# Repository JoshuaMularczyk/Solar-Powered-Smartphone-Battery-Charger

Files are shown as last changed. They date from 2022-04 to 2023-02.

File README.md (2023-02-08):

# Solar Smartphone Charger
This project applies skills of Power Electronics to create, deign, and construct a solar powered battery charger. My partner [Christian Williams](https://github.com/cwill713) and I were tasked by our professor [Dr. Rob Frohne](https://github.com/frohro) with coming up with a project for our Power Electronics class that incorporated what we were learning in the coursework. We decided to take what we were learning about step-down converters and design a charger for a smartphone in which the power source was a solar panel.

## Design Objectives:
- Output 5V from a higher input voltage
- Allow 1 amphere to be drawn into the smartphone
- Inexpensive to build ($20-$30 Budget)

## Overview

Blockdiagram

The power electronics project that [Christian Williams](https://github.com/cwill713) and I decided on was based around the specifications of new generation iPhone. We knew that Apple is picky with their products, so if we could get it to work with an iPhone it should, in theory, work with Android as well. I decided to use the [LM3478](https://www.ti.com/lit/ds/symlink/lm3478.pdf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) High-Efficiency Low-Side N-Channel Controller for our Switching Regulator. This is the heart of our circuit and allows for a reccomended 2.97-40V input volage and a peak driver output current of 1A. This chip can withstand a typical input current of 2.7A and a max of 3.3A. We used a 5W 12V Solar Panel to ensure that our smartphone would charge in average conditions.

## Rev 7 Design

schematic2

This is the most updated KiCad schematic for my circuit design. I used the Texas Instrument [Webench Power Designer](https://www.ti.com/design-resources/design-tools-simulation/webench-power-designer.html) to generate this step-down circuit. I used the majority of the components specified by the power designer with the exception of some values. These can be found in the [BOM](https://github.com/JoshuaMularczyk/Solar-Smartphone-Charger/tree/main/BOMs) I specified a 5V minimum as well as a 12V maximum based on what would most likely be coming out of the solar panel. I also specified 1A for my maximum output current and 5V for my output voltage. The efficiency of this circuit was given at 84.1% by Webench.

### Voltage Dividers for USB

volatgefix2applereq

The voltages that needed to be applied to the Vbus, D+, and D- pin were found in the following websites: [Pinout for USB](http://static.righto.com/files/charger-schematic.pdf) and [Values based on different Ampheres](https://kb.plugable.com/usb-hubs-cables-switches/usb-device-charging). *Note since we are using 1A ouput the Vbus pin needs 5V, the D- pin needs 2V, and the D+ pin needs 2.7V*
## Rev 7 Simulation
I simulated our circuit in LTSpice

labeledsim

LTSpice has most of the components needed, but I had to import a library for the LM3478. I found this library in a [project log](https://hackaday.io/project/27899-nixie-tube-power-supply/log/69767-ltspice) by [Paul Andrews](https://github.com/judge2005) on Hackaday. That library was causeing some errors in LTSpice so I did some research and realized I needed to add two more "0" place holders after each "PULSE" statement. The updated library that I used LM3478 can be downloaded [here](https://github.com/JoshuaMularczyk/Solar-Smartphone-Charger/blob/main/Simulations/LM3478_TRANS.lib). The second library I needed was for the csd17553q5a mosfet. I found this library on the [Texas Instrument](https://www.ti.com/product/CSD17553Q5A#design-tools-simulation) page. This library can be downloaded [here](https://github.com/JoshuaMularczyk/Solar-Smartphone-Charger/blob/main/Simulations/CSD17553Q5A.lib). The schottkey diode used in the simulation is also not the exact same component as used in the schematic but another schottkey diode with the same specifications was used in its place. The simulation ran over night to get to 7 ms. The prolonged period of time was likely due to the laptop it was running on as well as the coupled inductors in the circuit.

### Voltage Outputs (5V 2.7V 2V)

labeledvoltages

This simulation shows the voltages going into each of our three USB output pins (5V, 2.7V, 2V).

### Input and Output Current

currentsim

This simulation shows the two different currents in our circuit. The green trace represents the current going into the LM3478. It starts at about 270mA and trails off close to 0A. The blue trace represents the current being pulled from the 5-ohm load resistor which is taking the place of an iPhone. The iPhone needs to draw around 1A of current and as seen in the simulation it will achieve this.

## Rev 7 PCB Design

pcb2

We had our boards sourced from [JLCPCB](https://jlcpcb.com/VGS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), who have an offer going of 5, 2-layer, 100x100mm boards for $2. I then designed the board to fit these specifications and send it in for printing.

## Rev 6 Testing

My partner and I decided to construct a [Build and Test Plan](https://github.com/JoshuaMularczyk/Solar-Smartphone-Charger/blob/main/Milestone%20Reports/Build%20and%20Test%20Plan.xlsx) while we waited for our parts to come in from JLCPCB and Digikey. It helped us think through ways of testing things in stages without causing the destructions of parts.



My partner and I each constructed a separate board and tested to see if it worked. After constructing the boards we used a 0-18V 1A power supply and realized that the boards were not allowing our iPhones to charge. We plugged in a nearby TI-84 Plus CE calculator that was rated to charge at 5V 0.5A and it started charging. We then decided to switch to a bigger power supply rated for 24V 3A and plugged in an Android which began to charge. The iPhone still would not charge. After some research about Apple devices, a fellow colleague, [Caydn Maddocks](https://github.com/Maddca) and I discovered that Apple was extra particular and required voltages to the D+ and D- pins of the USB connector. The specific voltages differ based on the current being drawn (we used 2.7V to D+ and 2V to D-). This can be seen in the "Voltage Dividers for USB" section above. The process of fixing this can be seen in the issues section [here](https://github.com/JoshuaMularczyk/Solar-Smartphone-Charger/issues?q=is%3Aissue+is%3Aclosed).

Next, we connected our 5W 12V solar panels to the converter and took them outside to get direct sunlight. Once the solar panel was propped up to be perpendicular to the sun, I plugged in my iPhone and it started charging. It takes quite a bit of time to charge with 5W so I recommend getting a higher wattage solar panel for faster charging.

## Rev 6 Results

The image on the left shows the voltage being supplied to the iPhone and the image on the right shows the current being drawn by the iPhone.



Here we can see that using the power supply, our circuits is around 93.7% efficient ((4.88V*0.96A)/(5W)). We also tested this circuit with voltages from 5-12V from the power supply and the output stayed at a constant 4.8-4.9V.

The Solar Smartphone Charger worked as expected and was able to charge smartphones, Apple and Android, during a sunny day. You can see more photos of the finished product on the [wiki](https://github.com/JoshuaMularczyk/Solar-Smartphone-Charger/wiki/Photos) here!

We measured a 4.74V 0.98A output from our circuit using a solar panel. This gives us an efficiency of 92.9% given that our solar panel was actually outputting 5W.

Click [here](https://youtu.be/SS7m2UqrDPg) to watch a video demonstration of the finished project!

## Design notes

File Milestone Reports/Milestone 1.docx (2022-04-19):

Joshua Mularczyk and Christian Williams

ENGR 460

Milestone 1

4 April 2022

Project Definition

Project: Solar powered phone charger

Stretch Goal: Make it a wireless charger

Definition:

For our project this quarter, we have decided to design power electronics to use solar power to charge a smartphone. This will be done using solar panels that will provide charge to a external rechargeable battery (maybe 2 AA’s?) which will then run through circuitry that has some type of switch that shuts off the charging when the maximum voltage has been reached and circuitry to allow the power to pass from the batteries through a USB port so that a smart phone can be plugged in. If time allows, a casing can be designed for the circuitry using 3D printing for a final portable product.

References that sparked idea:

https://www.youtube.com/watch?v=OyslcihUtzQ

- Youtube video explaining how to create a DC to DC Boost Converter

https://www.instructables.com/Wireless-Solar-Charger/

- Project using solar panels to create a wireless charger for a smartphone

https://www.engineeringforchange.org/news/how-to-build-a-solar-powered-usb-charger-for-phones-and-other-small-devices/

- Shows the process of designing a similar solar powered phone charger

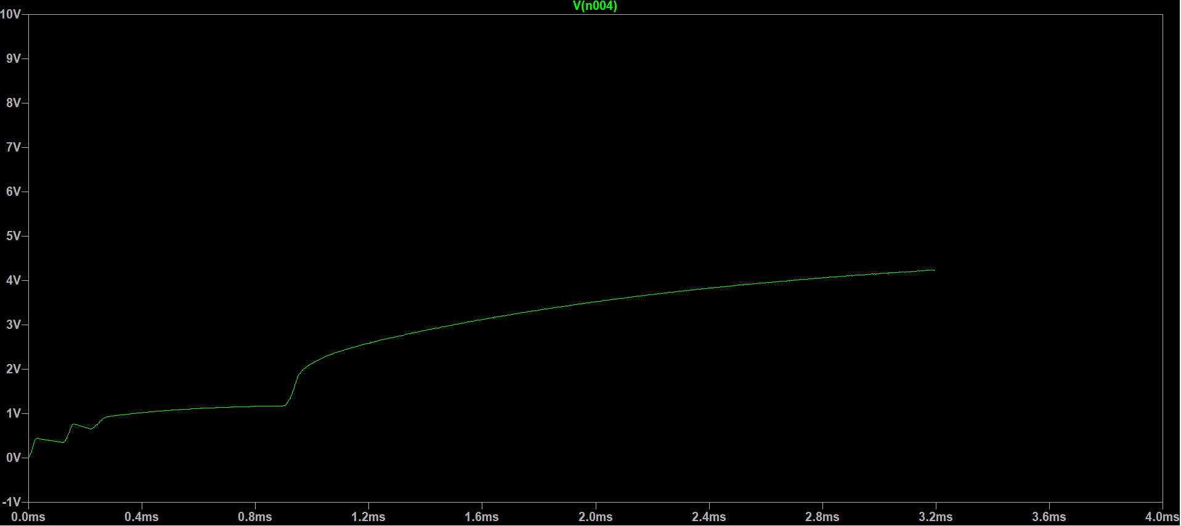
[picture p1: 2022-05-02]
Simulations/Pictures of Output Voltage/LoadResistorSimClose.PNG

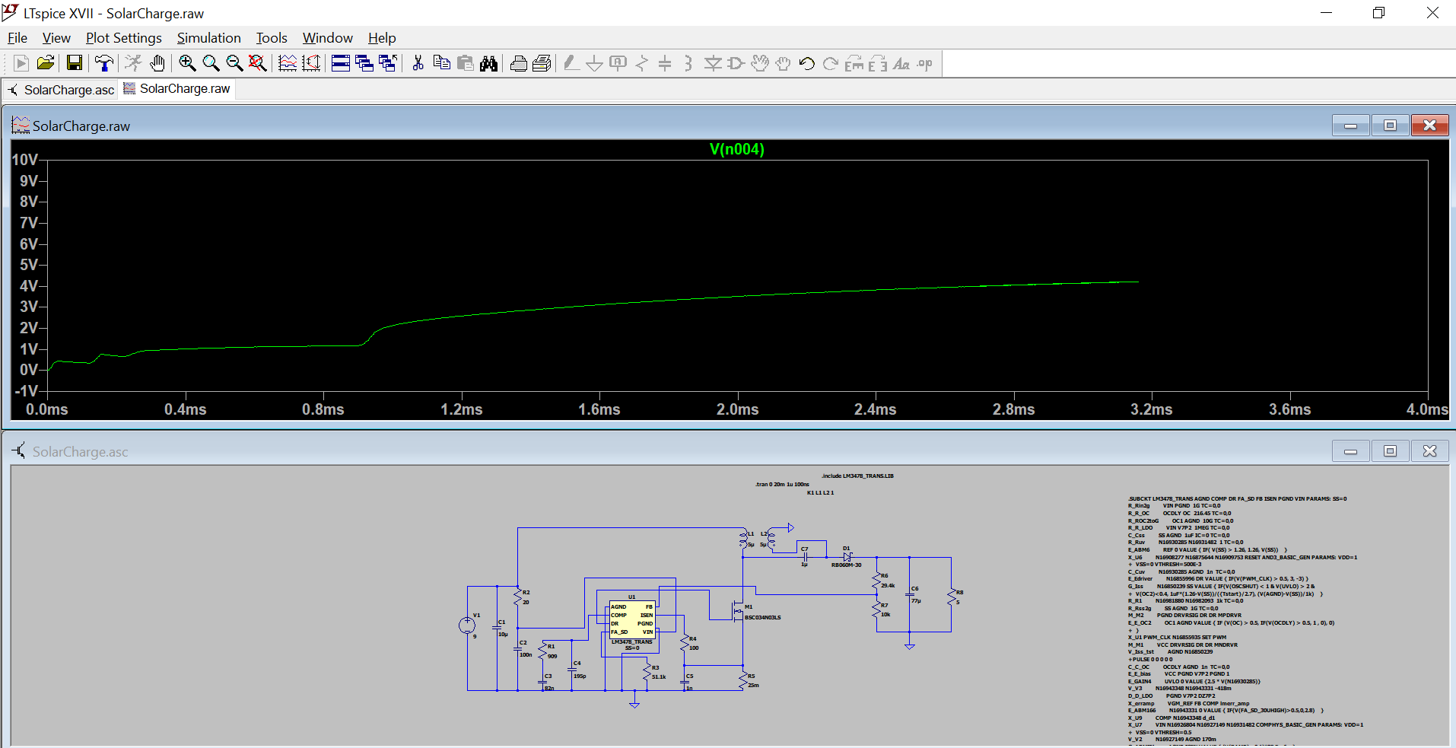
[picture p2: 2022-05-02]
Simulations/Pictures of Output Voltage/loadResistorSim.PNG

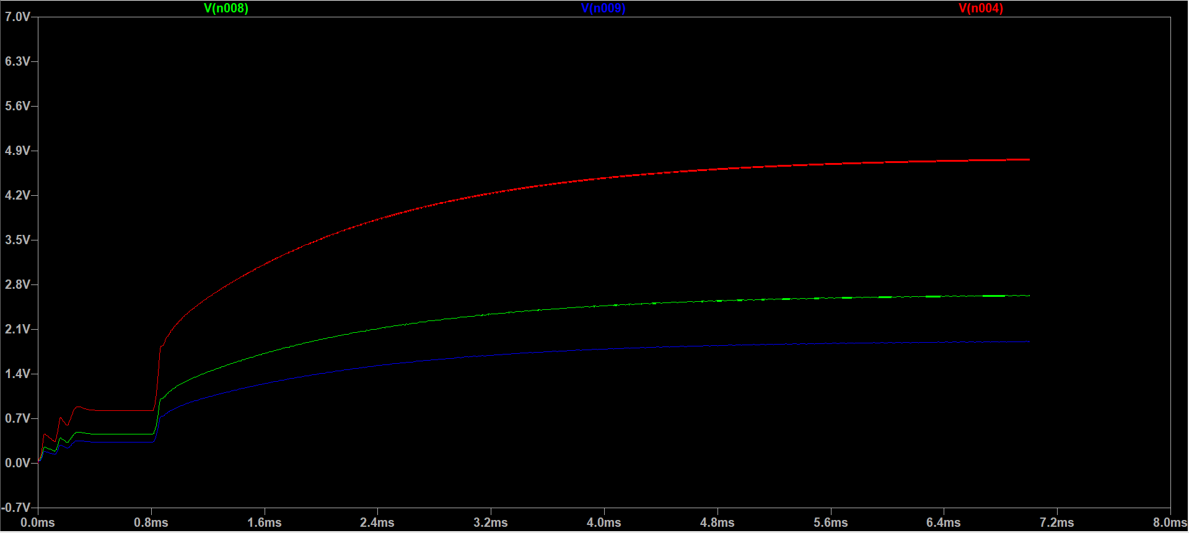
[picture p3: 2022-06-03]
Simulations/Pictures of Output Voltage/ThreeOutputVoltages.PNG

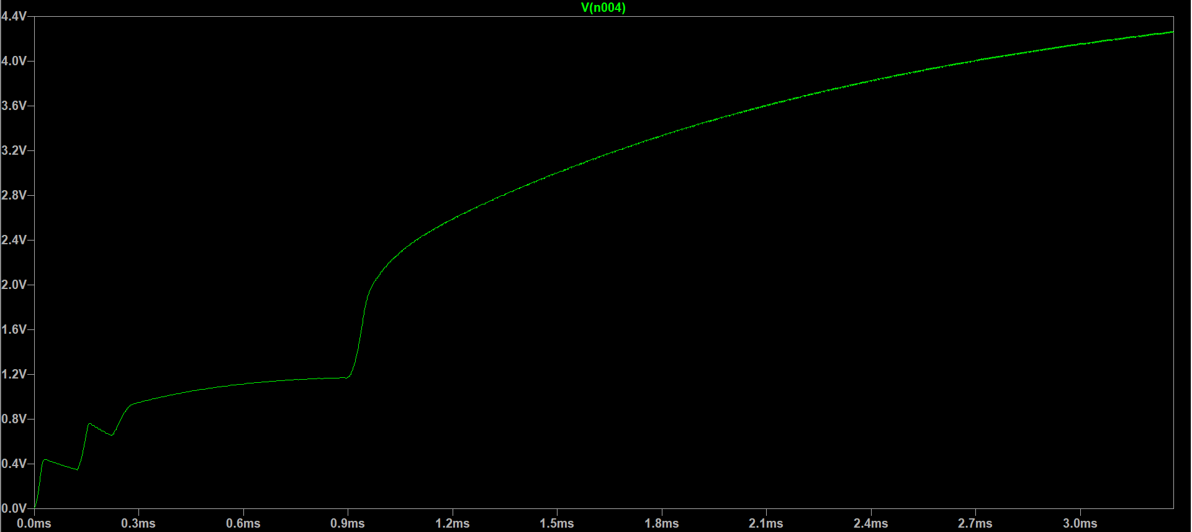
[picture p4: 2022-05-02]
Simulations/Pictures of Output Voltage/Capture.PNG

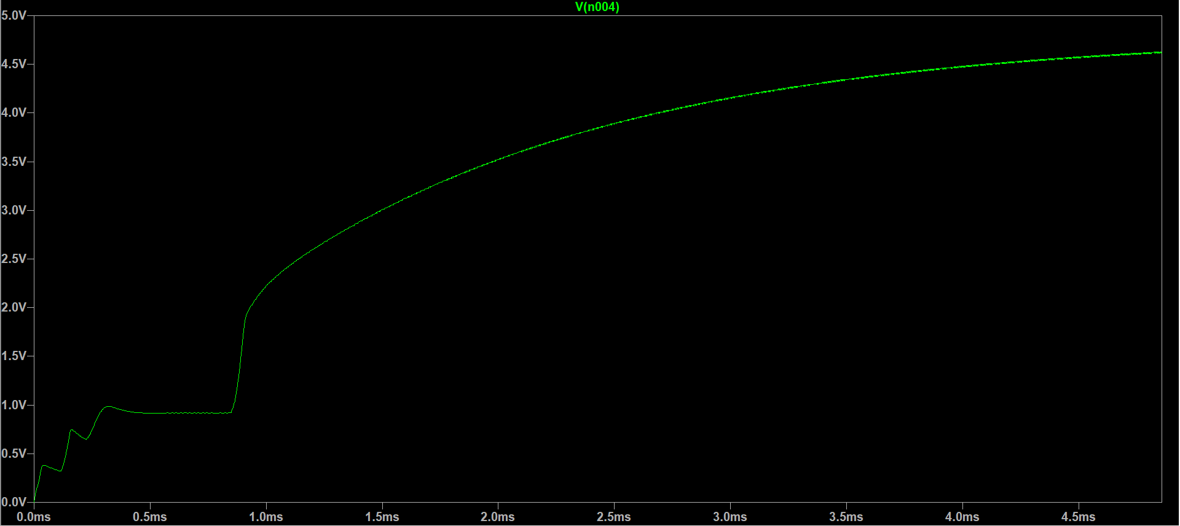
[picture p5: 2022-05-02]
Simulations/Pictures of Output Voltage/0.05s.PNG

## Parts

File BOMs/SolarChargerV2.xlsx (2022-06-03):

Id | Label | Footprint | Amount | Value | Price | Supplier and ref
1 | Le | DRQ | 1 | 10u | $1.81 | https://www.digikey.com/en/products/detail/eaton-electronics-division/DRQ125-100-R/667233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
2 | C7 | Capacitor_SMD:C_1206_3216Metric | 1 | 47u | $0.74 | https://www.digikey.com/en/products/detail/murata-electronics/GRM31CR61A476KE15L/4359666
3 | C1 | Capacitor_SMD:C_1812_4532Metric | 1 | 10u | $0.45 | https://www.digikey.com/en/products/detail/kyocera-avx/TPSB106K016R0800/678477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
4 | C5 | Capacitor_SMD:C_0805_2012Metric | 1 | 1n | $0.10 | https://www.digikey.com/en/products/detail/walsin-technology-corporation/0805N102J500CT/9355088
5 | C3 | Capacitor_SMD:C_0603_1608Metric | 1 | 82n | $0.14 | https://www.digikey.com/en/products/detail/kyocera-avx/0603YC823KAT2A/563348
6 | C2 | Capacitor_SMD:C_0805_2012Metric | 1 | 100n | $0.10 | https://www.digikey.com/en/products/detail/w%C3%BCrth-elektronik/885012207045/5453900
7 | C4 | Capacitor_SMD:C_0805_2012Metric | 1 | 200p | $0.15 | https://www.digikey.com/en/products/detail/yageo/CC0805KRX7R9BB201/5884236
8 | C6 | Capacitor_SMD:C_0805_2012Metric | 1 | 1u | $0.19 | https://www.digikey.com/en/products/detail/murata-electronics/GRM21BR71C105MA01L/586691
9 | J1 | USB_A_Molex_67643_Horizontal | 1 | USB_A | $1.66 | https://www.digikey.com/en/products/detail/molex/0676430910/917619
10 | D1 | Diode_SMD:D_SMC | 1 | B340 | $0.54 | https://www.digikey.com/en/products/detail/diodes-incorporated/B340B-13-F/768869
11 | U1 | SOIC-8_3.9x4.9mm_P1.27mm | 1 | LM3478MA_NOPB | $2.95 | https://www.digikey.com/en/products/detail/texas-instruments/LM3478MA-NOPB/2682777
12 | Q1 | TDSON-8-1 | 1 | CSD16410Q5A | $1.01 | https://www.digikey.com/en/products/detail/texas-instruments/CSD16410Q5A/2038309
13 | R6 | Resistor_SMD:R_0805_2012Metric | 1 | 29.4k | $0.10 | https://www.digikey.com/en/products/detail/panasonic-electronic-components/ERJ-6ENF2942V/111566
14 | R4 | Resistor_SMD:R_0805_2012Metric | 1 | 100 | $1.63 | https://www.digikey.com/en/products/detail/vishay-dale/M55342K06B100DRS3/2941801
15 | R3 | Resistor_SMD:R_0805_2012Metric | 1 | 51.1k | $0.10 | https://www.digikey.com/en/products/detail/yageo/RC0805FR-0751K1L/728015
16 | R1 | Resistor_SMD:R_0603_1608Metric | 1 | 20 | $0.10 | https://www.digikey.com/en/products/detail/yageo/RC0603FR-0720RL/727039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
17 | R7 | Resistor_SMD:R_0805_2012Metric | 1 | 10k | $0.10 | https://www.digikey.com/en/products/detail/stackpole-electronics-inc/RNCP0805FTD10K0/2240262
18 | R5 | Resistor_SMD:R_1206_3216Metric | 1 | 25m | $0.49 | https://www.digikey.com/en/products/detail/stackpole-electronics-inc/CSR1206FK25L0/1646093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
19 | R2 | Resistor_SMD:R_1206_3216Metric | 1 | 887 | $0.20 | https://www.digikey.com/en/products/detail/panasonic-electronic-components/ERJ-8ENF8870V/88853
20 | SC1 | SIP-2 | 1 | Solar_Cell | $17.99 | amazon.com/dp/B00OZC19AY/ref=emc_bcc_2_i?th=1 (https://www.amazon.com/Treedix-Polysilicon-Polycrystalline-Encapsulated-Waterproof/dp/B0834MQDT8)
 |  |  |  | Total Cost | $30.55 | cart | https://www.digikey.com/short/1jf4t9wm

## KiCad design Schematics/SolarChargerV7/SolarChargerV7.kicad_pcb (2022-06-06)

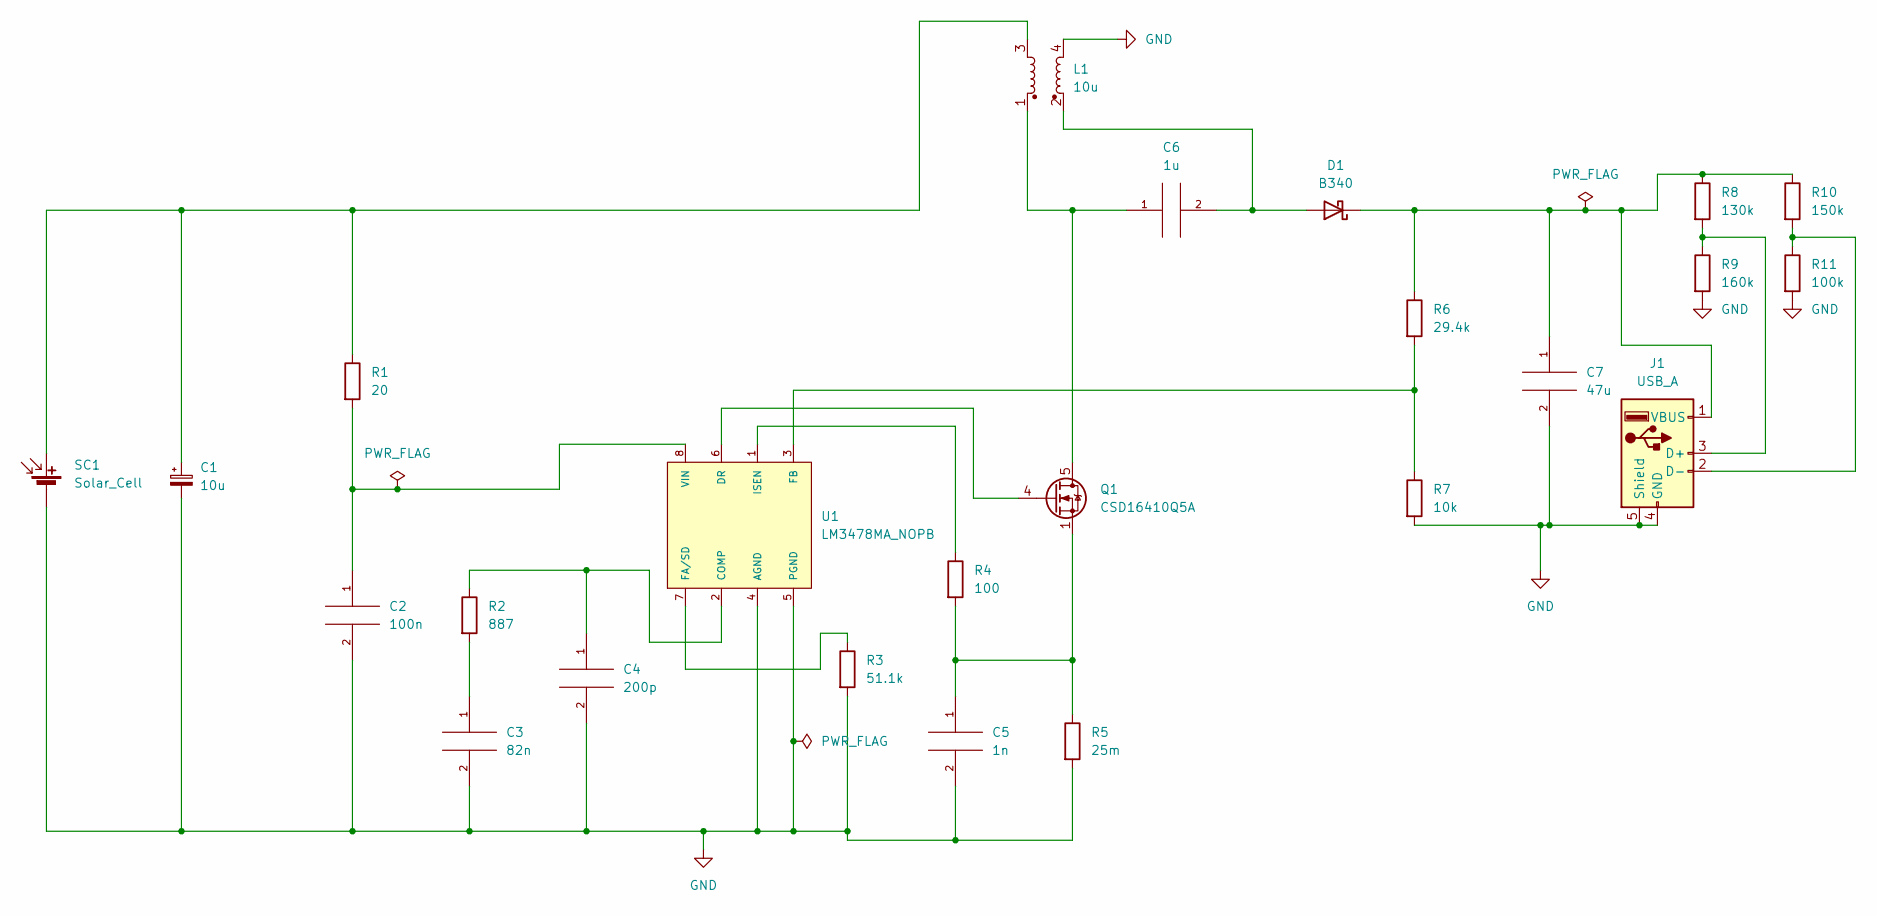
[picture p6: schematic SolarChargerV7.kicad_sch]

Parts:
C1: 10u; C_1812_4532Metric
C2: 100n; C_0805_2012Metric
C3: 82n; C_0603_1608Metric
C4: 200p; C_0805_2012Metric
C5: 1n; C_0805_2012Metric
C6: 1u; C_0805_2012Metric
C7: 47u; C_1206_3216Metric
D1: B340; D_SMC
J1: USB_A; USB_A_Molex_67643_Horizontal
L1: 10u; DRQ
Q1: CSD16410Q5A; TDSON-8-1
R1: 20; R_0603_1608Metric
R2: 887; R_1206_3216Metric
R3: 51.1k; R_0805_2012Metric
R4: 100; R_0805_2012Metric
R5: 25m; R_1206_3216Metric
R6: 29.4k; R_0805_2012Metric
R7: 10k; R_0805_2012Metric
R8: 130k; R_0805_2012Metric
R9: 160k; R_0805_2012Metric
R10: 150k; R_0805_2012Metric
R11: 100k; R_0805_2012Metric
SC1: Solar_Cell; SIP-2
U1: LM3478MA_NOPB; SOIC-8_3.9x4.9mm_P1.27mm

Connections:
GND: C1.2, C2.2, C3.2, C4.2, C5.2, C7.2, J1.4 (GND), J1.5 (Shield), L1.4, R3.2, R5.2, R7.2, R9.2, R11.2, SC1.2 (-), U1.4 (AGND), U1.5 (PGND)
unnamed: C1.1, L1.3, R1.1, SC1.1 (+)
unnamed: C2.1, R1.2, U1.8 (VIN)
unnamed: C3.1, R2.2
unnamed: C4.1, R2.1, U1.2 (COMP)
unnamed: C5.1, Q1.1 (S), Q1.2 (S), Q1.3 (S), R4.2, R5.1
unnamed: C6.1, L1.1, Q1.5 (D)
unnamed: C6.2, D1.2 (A), L1.2
unnamed: C7.1, D1.1 (K), J1.1 (VBUS), R6.1, R8.1, R10.1
unnamed: J1.2 (D-), R10.2, R11.1
unnamed: J1.3 (D+), R8.2, R9.1
unnamed: Q1.4 (G), U1.6 (DR)
unnamed: R3.1, U1.7 (FA/SD)
unnamed: R4.1, U1.1 (ISEN)
unnamed: R6.2, R7.1, U1.3 (FB)

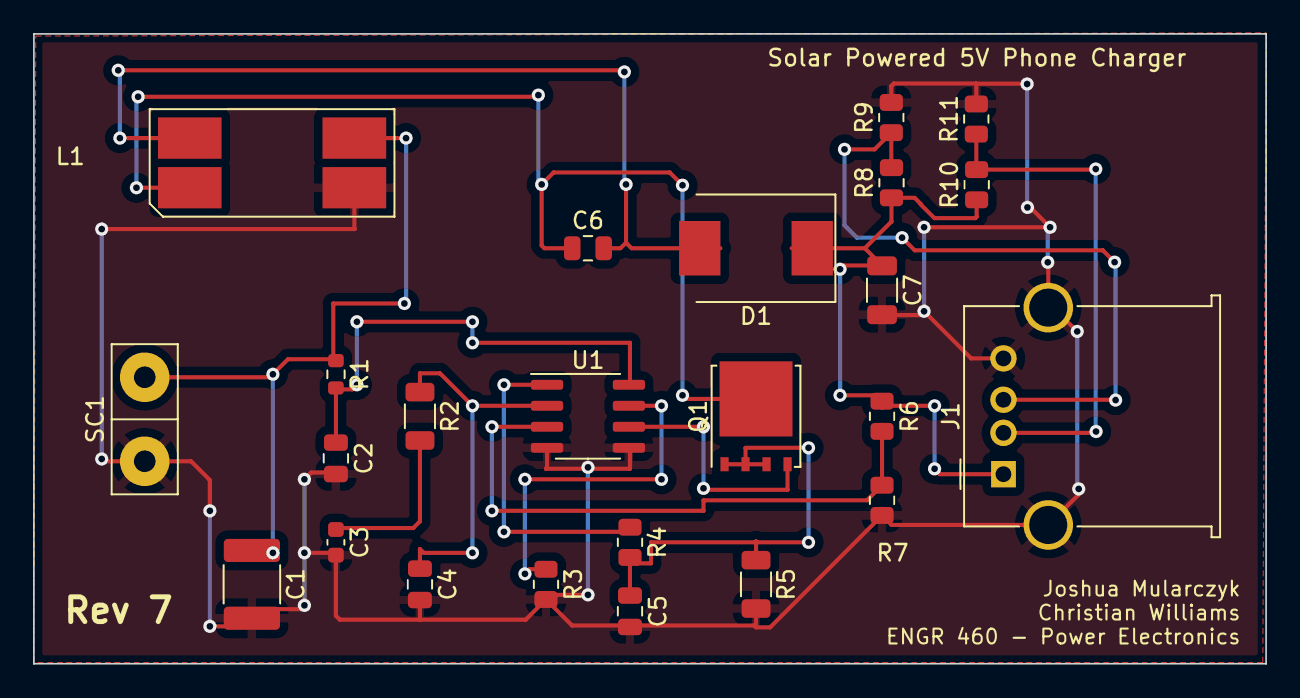
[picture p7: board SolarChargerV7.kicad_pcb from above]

Board: 2 copper layers, 74.5 x 38.1 mm, 24 parts (0 on the bottom side), 15 nets.

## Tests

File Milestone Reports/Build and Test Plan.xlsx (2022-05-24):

Build and Test Plan | Testers: Joshua Mularczyk and Christian Williams
Steps: | Description: | Column3 | Column4 | Column5 | Column6 | Column7 | Column8 | Column9 | Column10 | Column11 | Column12
1 | Unbox and Take Inventory of Parts from Digikey and Amazon
2 | Designate Storage area (Analog Lab)
3 | Take Solar Panel outside and test: Output Voltage(open Circuit), Output Current(short circuit), maximum power point (using a resistor(Voc/Isc) to best represent our load, and Calculate Output Power | Expected Voltage: 9V | Expected Current: 1.1 Amps | Expected Power: 10W
4 | Construct the Circuit by soldering onto PCB
5 | Inspect all solder connection under the Microscope to check for errors
6 | Check any parts with ohm meter
7 | Plug in power souce and watch current (if it peggs out then immediately shut it off
8 | Turn on the power source again and check output voltage by using the through hole connections before soldering on the USB connector and a load resistor.
9 | If output voltage is at or near 5V then go though and check any other values.
10 | Solder on solar panel

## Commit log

2022-04-19 Upload of the second version of the solar charger schematic
2022-04-19 upload of schematic
2022-04-19 BOM file
2022-04-19 upload of a screen shot of the schematic
2022-04-25 updates and changes
    [SolarChargerV2.kicad_sch]
2022-04-26 Final schematic and PCB created plus BOM and gerber files
    [SolarChargerV2-B_Cu.gbr, SolarChargerV2-B_Mask.gbr, SolarChargerV2-B_Silkscreen.gbr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]
2022-04-27 creation of drill files and two zip folders
    [SolarChargerV2-B_Cu.gbr, SolarChargerV2-B_Mask.gbr, SolarChargerV2-B_Silkscreen.gbr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]
2022-04-27 File rearangement and V3 of the project
    [SolarChargerV2-B_Cu.gbr, SolarChargerV2-B_Fab.gbr, SolarChargerV2-B_Mask.gbr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]
2022-04-27 Version 4 created to swtich out mosfet, diode, and resistor
    [SolarChargerV2-B_Cu.gbr, SolarChargerV2-B_Fab.gbr, SolarChargerV2-B_Mask.gbr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]
2022-04-28 Versions 4 created
    [SolarChargerV2-B_Cu.gbr, SolarChargerV2-B_Fab.gbr, SolarChargerV2-B_Mask.gbr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]
2022-04-28 new files
    [SolarChargerV2-B_Cu.gbr, SolarChargerV2-B_Fab.gbr, SolarChargerV2-B_Mask.gbr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]
2022-04-28 Final changes and Version 5
    [SolarChargerV2-B_Cu.gbr, SolarChargerV2-B_Fab.gbr, SolarChargerV2-B_Mask.gbr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]
2022-04-28 Version 6 created
    [SolarChargerV2.xlsx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]
2022-05-02 Milstone 4
    [Build and Test Plan.xlsx]
2022-05-02 New HTML bom
2022-05-24 Version 7 created to add voltage divider (Iphone compatablility)
    [SolarChargerV7-B_Cu.gbr, SolarChargerV7-B_Fab.gbr, SolarChargerV7-B_Mask.gbr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]
2022-06-03 Version 7 final changes
    [SolarChargerV2.xlsx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]
2022-06-06 quick fix of resistor values for voltage divider
    [SolarChargerV7.kicad_pcb, SolarChargerV7.kicad_sch]
2022-06-22 Create LICENSE
    created license for power electronics project
